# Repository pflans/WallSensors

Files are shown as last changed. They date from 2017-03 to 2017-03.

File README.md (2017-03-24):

# WallSensors

## Purpose

A sensor package that includes 4 attachments for DHT-22 temperature and humidity sensors. Currently being used at Sasaki to measure 4 different points within the wall cavity to determine the effectiveness of the wall materials and insulation. Battery powered to avoid the need for external power the unit wakes up every 60 minutes to measure temperature and humidity from all 4 sensors, logs the data to the SD card, then puts itself back into deep sleep mode (Wi-Fi off). Once a day at midnight the unit will turn on Wi-Fi and transmit all of that days data points to Ubidots. This once-a-day use of Wi-Fi takes the unit from a about a week of uptime (with Wi-Fi always on) to about a month of uptime with a 6000 mAh battery.

## Hardware
* DHT-22 temperature and humidity sensor 
* Particle Photon microcontroller
* SparkFun Level Shifting microSD breakout
* microSD card 
* 1kΩ resistors
* SparkFun Photon Battery Shield (if fuel gauging is required)
* LiPo battery

## Dependencies 
* ADAFRUIT_DHT (0.0.2)    
* SPARKFUNMAX17043 (1.1.2)    
* HTTPCLIENT (0.0.5)    
* SDFAT (0.0.3)    

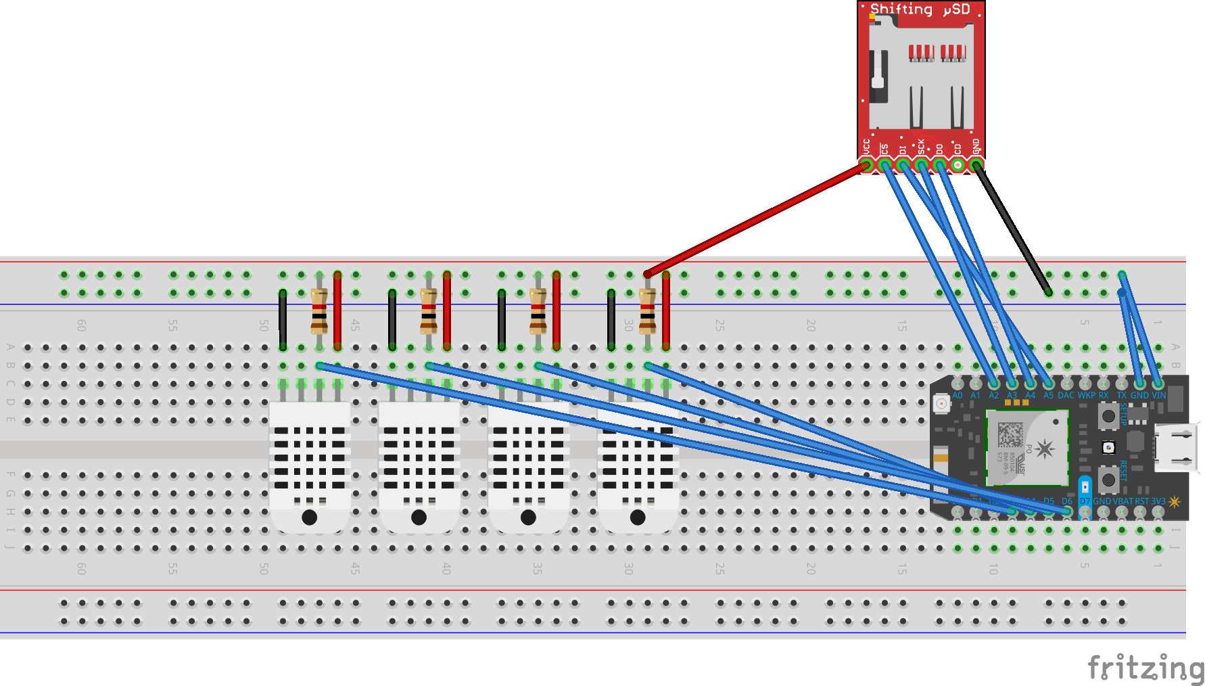
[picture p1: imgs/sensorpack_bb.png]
Breadboard View


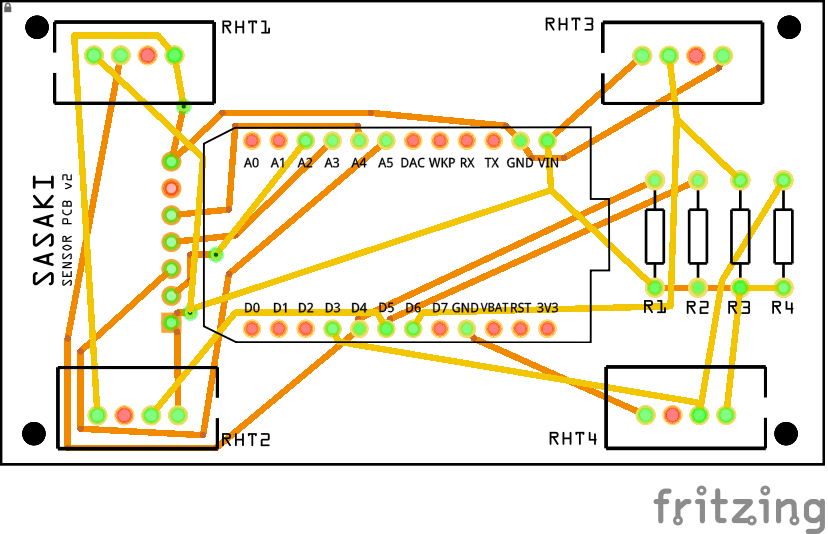
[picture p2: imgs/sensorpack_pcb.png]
PCB View


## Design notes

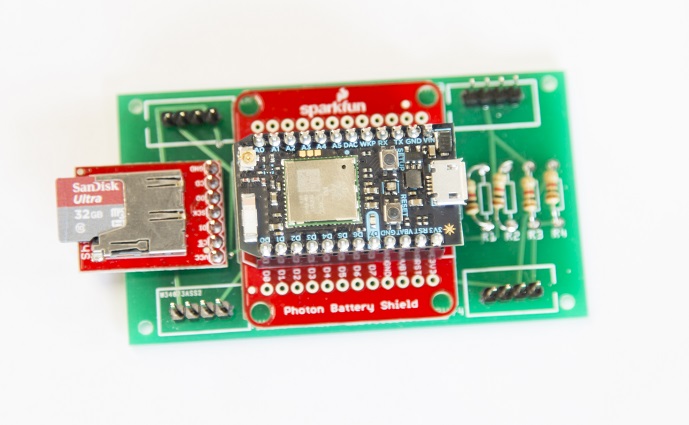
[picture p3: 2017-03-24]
imgs/330A7970.jpg

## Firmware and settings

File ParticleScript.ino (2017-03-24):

#define UNITNAME 000

// ---- External Libraries ----
#include <Adafruit_DHT.h>
#include <HttpClient.h>
#include <SdFat.h>
#include <SparkFunMAX17043.h>


// ---- HTTP ----
HttpClient http;
#define SENSOR1_TEMP "xxxxx"
#define SENSOR1_HUM "xxxxx"

#define SENSOR2_TEMP "xxxxx"
#define SENSOR2_HUM "xxxxx"

#define SENSOR3_TEMP "xxxxx"
#define SENSOR3_HUM "xxxxx"

#define SENSOR4_TEMP "xxxxx"
#define SENSOR4_HUM "xxxxx"

#define BATTERY_PCT "xxxxx"
#define BATTERY_VOLT "xxxxx"

#define TOKEN "xxxxx"

http_header_t headers[] = {
      { "Content-Type", "application/json" },
      { "X-Auth-Token" , TOKEN },
    { NULL, NULL } // NOTE: Always terminate headers with NULL
};

http_request_t request;
http_response_t response;
String postPackage;

// ---- SENSORS ----
// Connect pin 1 (on the left) of the sensor to +5V
// Connect pin 2 of the sensor to whatever your DHTPIN is
// Connect pin 4 (on the right) of the sensor to GROUND
// Connect a 10K resistor from pin 2 (data) to pin 1 (power) of the sensor

#define DHTPIN1 5     // what pin we're connected to
#define DHTPIN2 4     
#define DHTPIN3 6     
#define DHTPIN4 3     
#define DHTTYPE DHT22 // DHT 22 (AM2302)

DHT dht1(DHTPIN1, DHTTYPE);
DHT dht2(DHTPIN2, DHTTYPE);
DHT dht3(DHTPIN3, DHTTYPE);
DHT dht4(DHTPIN4, DHTTYPE);

float h1 =  0;
double f1 = 0;

float h2 =  0;
double f2 = 0;

float h3 =  0;
double f3 = 0;

float h4 =  0;
double f4 = 0;

float volt = 0;
float pct = 0;


// ---- TIME ----
const long oneSecond = 1000;  // a second is a thousand milliseconds
const long oneMinute = oneSecond * 60;
const long oneHour   = oneMinute * 60;
const long oneDay    = oneHour * 24;


// ---- SDCARD ----
// Primary SPI with DMA
// SCK => A3, MISO => A4, MOSI => A5, SS => A2 (default)
SdFat sd;
const uint8_t chipSelect = SS;
File dataFile;
File myFile;

// ---- DEBUG ----
bool debug = false;

// ---- FIRMWARE ----
SYSTEM_MODE(SEMI_AUTOMATIC);

void setup() {
    if (debug){
        Serial.println("SETUP");
    }
    
    request.hostname = "things.ubidots.com";
    request.port = 80;
    
    Serial.begin(9600);
    dht1.begin();
    dht2.begin();
    dht3.begin();
    dht4.begin();

    lipo.begin(); // Initialize the MAX17043 LiPo fuel gauge
    lipo.quickStart();
}

void loop() {   
    
    //
    // PART 1: DATA LOGGING
    //
    
    delay(oneSecond * 5);

    if (debug){
        Serial.println("SETUP");
    } 
    
	h1 = dht1.getHumidity();
	f1 = dht1.getTempFarenheit();
	h2 = dht2.getHumidity();
	f2 = dht2.getTempFarenheit();
	h3 = dht3.getHumidity();
	f3 = dht3.getTempFarenheit();
	h4 = dht4.getHumidity();
	f4 = dht4.getTempFarenheit();


	pct = lipo.getSOC();
	volt = lipo.getVoltage();
    
    if (debug){
        if (isnan(h1) || isnan(f1)) {
		    Serial.println("Failed to read from DHT SENSOR 1!");
		} else {
		    Serial.println("SENSOR_1");
            Serial.println(f1);
            Serial.println(h1);
		}
		if (isnan(h2) || isnan(f2)) {
		    Serial.println("Failed to read from DHT SENSOR 2!");
		} else {
            Serial.println("SENSOR_2");
            Serial.println(f2);
            Serial.println(h2);
		}
		if (isnan(h3) || isnan(f3)) {
		    Serial.println("Failed to read from DHT SENSOR 3!");
		} else {
            Serial.println("SENSOR_3");
            Serial.println(f3);
            Serial.println(h3);
		}
		if (isnan(h4) || isnan(f4)) {
		    Serial.println("Failed to read from DHT SENSOR 4!");
		} else {
            Serial.println("SENSOR_4");
            Serial.println(f4);
            Serial.println(h4);
		}
		if (isnan(volt) || isnan(pct)) {
		    Serial.println("Failed to read from BATTERY FUEL GAUGE!");
		} else {
            Serial.println("BATTERY VOLT");
            Serial.println(volt);
            Serial.println("BATTERY PCT");
            Serial.println(pct);
		}
    }
    
    String fileTime = Time.format("%d-%m-%y");
    String readTime = String(Time.now()) + "000";
    
    sd.begin(chipSelect, SPI_HALF_SPEED);
    dataFile.open(fileTime+".txt", O_RDWR | O_CREAT | O_AT_END);
    
    // UNIT_NUMBER, READ_TIME, SENSOR_1_TEMP, SENSOR_1_HUM, SENSOR_2_TEMP, SENSOR_2_HUM, SENSOR_3_TEMP, SENSOR_3_HUM, BATTERY_PCT, BATTERY_VOLT
    // {"variable": "568405d376254261ef114f35", "value":41.2}, {"variable": "56843ac776254258956b9c05", "value":88.3} 
    postPackage =
        "[{\"variable\": \"" + String(SENSOR1_TEMP) + "\", \"timestamp\": " + readTime + ", \"value\": " + String(f1) + "}" 
        + "," +
        "{\"variable\": \"" + SENSOR2_TEMP + "\", \"timestamp\": " + readTime + ", \"value\": " + String(f2) + "}" 
        + "," + 
        "{\"variable\": \"" + SENSOR3_TEMP + "\", \"timestamp\": " + readTime + ", \"value\": " + String(f3) + "}" 
        + "," + 
        "{\"variable\": \"" + SENSOR4_TEMP + "\", \"timestamp\": " + readTime + ", \"value\": " + String(f4) + "}"
        + "," + 
        "{\"variable\": \"" + SENSOR1_HUM + "\", \"timestamp\": " + readTime + ", \"value\": " + String(h1) + "}" 
        + "," +
        "{\"variable\": \"" + SENSOR2_HUM + "\", \"timestamp\": " + readTime + ", \"value\": " + String(h2) + "}" 
        + "," + 
        "{\"variable\": \"" + SENSOR3_HUM + "\", \"timestamp\": " + readTime + ", \"value\": " + String(h3) + "}" 
        + "," + 
        "{\"variable\": \"" + SENSOR4_HUM + "\", \"timestamp\": " + readTime + ", \"value\": " + String(h4) + "}" 
        + "," + 
        "{\"variable\": \"" + BATTERY_PCT + "\", \"timestamp\": " + readTime + ", \"value\": " + String(pct) + "}" 
        + "," + 
        "{\"variable\": \"" + BATTERY_VOLT + "\", \"timestamp\": " + readTime + ", \"value\": " + String(volt) + "}]";
        
    dataFile.println(postPackage);
    dataFile.close();
    
    if (debug){
        Serial.println("POST_PACKAGE");
        Serial.println(postPackage);
    }
    
    // 
    // PART 2: SENDING DATA
    //
    
    if (debug){
        WiFi.on();
        if (Particle.connected() == false) {
            Particle.connect();
        }
        
        delay(oneSecond * 15);
            
        Serial.println("WIFISTATUS:");
        Serial.println(WiFi.ready());
        
        if (debug){
            Serial.println("FILE");
            Serial.println(fileTime+".txt");
        }
        
        if (!dataFile.open(fileTime+".txt", O_READ)) {
            if (debug){
                sd.errorHalt("opening "+fileTime+".txt for read failed");
            }
        }
    
        while (dataFile.available()) {
          String line = dataFile.readStringUntil('\n');
          Serial.println("LINE");
          Serial.println(line);
          
          request.path = "/api/v1.6/collections/values";
          request.body = line;
          http.post(request, response, headers);
         
          Serial.println("RESPONSE");
          Serial.println( response.status );
          delay(oneSecond);
        }
        
        dataFile.close();
    } else {
        if (Time.hour() == 23){
            WiFi.on();
            if (Particle.connected() == false) {
                Particle.connect();
            }
           
            delay(oneSecond * 15);
            
            if (!dataFile.open(fileTime+".txt", O_READ)) {
                if (debug){
                    sd.errorHalt("opening "+fileTime+".txt for read failed");
                }
            }
        
            while (dataFile.available()) {
              String line = dataFile.readStringUntil('\n');
              
              request.path = "/api/v1.6/collections/values";
              request.body = line;
              http.post(request, response, headers);
              delay(oneSecond);
            }
            
            dataFile.close();
            WiFi.off();
        }
    }

    if (!debug){
        delay(oneMinute);
        Particle.sleep(SLEEP_MODE_DEEP, 3600);
    } else {
        Serial.println("WIFISTATUS:");
        Serial.println(WiFi.ready());
        Serial.println("END_LOOP");  
        delay(oneSecond * 30);
    }
    
    
// Compute heat index
// Must send in temp in Fahrenheit!
/*
	hi = dht.getHeatIndex();
	dp = dht.getDewPoint();
	k = dht.getTempKelvin();
*/
    
}
